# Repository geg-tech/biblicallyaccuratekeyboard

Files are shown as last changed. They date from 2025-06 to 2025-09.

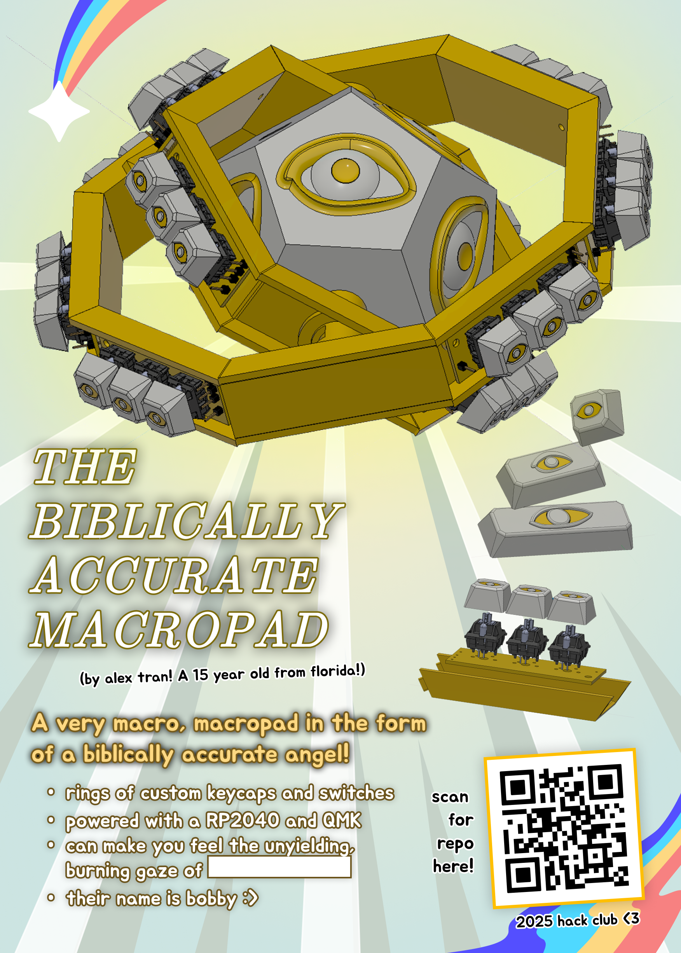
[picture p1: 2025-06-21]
extras/highway magazine.png

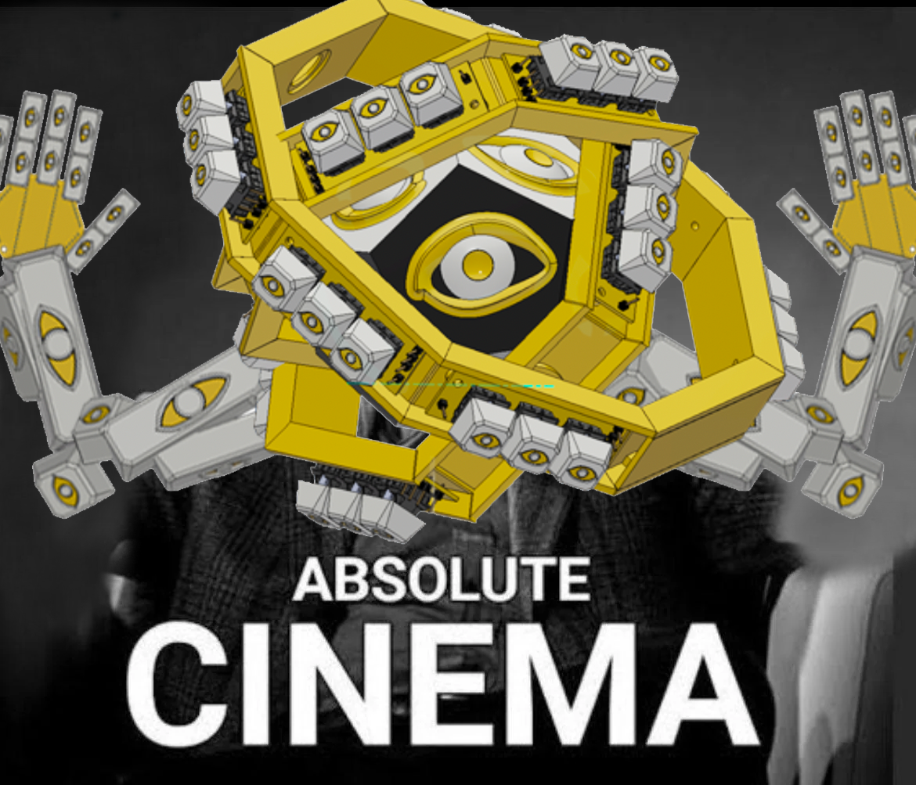
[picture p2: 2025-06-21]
extras/absolute cinema.png

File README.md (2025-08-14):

# The Biblically Accurate Keyboard


This is a custom, 3d-printed keyboard made to resemble a biblically accurate angel, powered by a Raspberry Pi Pico RP2040. <br/>
> see the keyboard working [here](https://youtu.be/EbvpPsTKe3c)!

My intial goal for this project was to just simply make something cool for the summer and to keep me occupied, but soon grew into a very complex CAD and art project that I had loads fun working on (and also served as great Fusion 360 practice for school). <br/>

I learned lots of useful techniques in Fusion 360, such as the Surface modeling tools, Create Form, and the 3D Sketch feature, which I will use extensively in my other work like future hardware projects, school work, and for my team in VEX Robotics. I also plan to show off this project to my high school's IRL Hack Club to encourage more students to join Hack Club :3 <br/>

The keyboard is powered with a RP2040 running QMK, which is soldered into a PCB in the center dodecahedron, and has external rings of key switches surrounding the center, all wired to the center PCB. <br/>

To fit the biblically accurate angel theming, the keyboard has a common motif of eyes, which is often seen in interpretations and drawings of biblically accurate angels. The case is also made out of gold PLA filament, with the center, keycaps, and some decorations painted white to fit the color scheme often associated with angels. <br/>

## CAD
regular view
exploded view <br/>

## PCB + Wiring Diagram
### Schematic
schematic <br/>

### Center PCB (dont mind the raspberry pi being a neon green)
center pcb view
center pcb top view
center pcb bottom view <br/>

### Switch PCBs


 <br/>

### Wiring Diagram
 <br/>

## BOM
| Item  |  Purpose | Price | Source |
| --- | --- | --- | --- |
| SUNLU Gold PLA Filament | Filament for the case | $19.99 | Amazon |
| Switch PCBs  | Houses the switches in the rings | $5.20 | JLCPCB |
| Center PCB  | Holds the RP2040 and connects to the PC | $2.00 | JLCPCB |
| Yellow 26 AWG Wire | Holds the switches and wires to the center | $3.57 | Aliexpress |
| Outemu Blue Switches | Switches to detect user input/presses | $0.99 | Aliexpress |
| RP2040 Microcontroller | Communicates to the computer, detect switch presses | $2.56 | Aliexpress |
| 3D Printer | Manufactures the keyboard case | Owned |  |
| Soldering Iron | Assembles the PCBs, can weld case to seal cracks | Owned |  |
| Keycaps | Makes switches more comfortable to use | Owned (printing |  |
| Cable | Allows connection between RP2040 and PC | Owned |  |
| Super Glue | Secures parts of the case to each other | Owned |  |
| M3 Screws (6mm, 10mm) | Allows for PCBs to be attached to the case | Owned |  |
| ------------- | ------------- | ------------- | ------------- |
|  |  |  | **Subtotal: $34.31**  |
| Amazon: $28.28 | JLCPCB: $18.81 | Aliexpress: $11.74 |  **Total (tax + shipping): $58.83** |

## additional notes and whatnot
* The case is costs around **466.37** grams of filament, and my current spool of black PLA is running really low (<100 grams left)
* The case will be assembled inside-out (starting from the center, threading the wires through the appropriate connectors before permanently attaching PCBs/ring sections
* JLCPCB is used instead of PCBWay due to the $20 coupon announcement to save costs by Hack Club HQ
* The keyboard will be programmed via QMK or KMK and after the keyboard is built

**special thanks**
* *Adedayo Adeleke* on Slack for giving me some microcontroller recommendations early on
* *Atrocious* on Slack for giving me a rundown on how to add 3D models to the PCB previewer in KiCad
* My friends and the many people who liked my work and encouraged me to continue working on the absolute trainwreck that is Fusion
* *alexren* on Slack for helping me and a bunch of others on getting their JLCPCB coupon working
* Special thanks to Hack Club and the people behind Highway for making this possible :D

**Inspirations** <br/>
* The indie game *ULTRAKILL*, specifically the angelic enemies named *Virtues* and the upcoming FRAUD update
* The Roblox game *Block Tales*, specifically the final boss of Demo 4, *The Ancients*

angel <br/>
The angel is also called bobby :)))) <br/>

A badge of a Cerberus and a raccoon laughing together, with the text "HIGHWAY" and "HACK CLUB" beside them.

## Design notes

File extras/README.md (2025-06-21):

# ay wasup hello
this is a folder containing a bunch of random stuff and artwork from the project that I felt like sharing <br/>
contains stuff like scrapped cad models, my highway magazine page, shitposts related to this project, etc. <br/>

highway magazine
looks inside
absolute cinema
biblically accurate macropad

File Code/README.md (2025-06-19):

# uhm what
the code here is currently a placeholder for what the final firmware *should* be! It was made with QMK, and will be changed once I get the macropad built for an easier time customizing which buttons are which (since I can test it on the spot) <br/>

## UPDATE!!!!!
this new code now uses QMK's custom firmware features! the .uf2 file is the compiled firmware uploaded to the RP2040, while the two .json files are part of the adafruit/pico_pad keyboard folder thingy idk <br/>
* keyboard.json replaces the premade one in qmk_firmware/keyboards/adafruit/pico_pad, while the keymap.json file goes into the keymaps folder (and into the desired keyboard folder if made)

vehicular

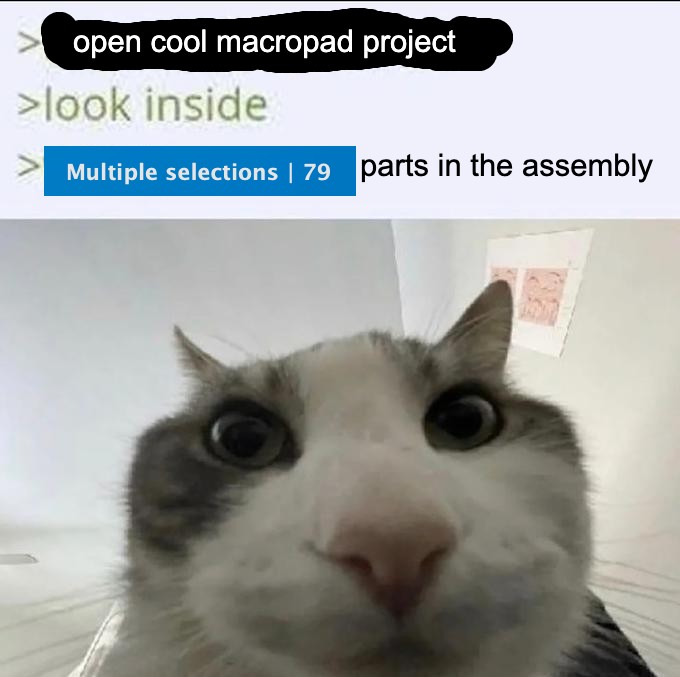
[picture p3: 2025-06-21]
extras/looks inside.jpg

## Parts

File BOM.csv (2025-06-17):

Item | Purpose | Source | Price | Subtotal | Total (tax + shipping) | Link
SUNLU Gold PLA Filament | Filament for the case | Amazon | $19.99 |  |  | https://www.amazon.com/SUNLU-Filament-PLA-Dimensional-Accuracy/dp/B0CJLT7Z9M
Switch PCBs (JLCPCB) | Houses the switches in the rings | JLCPCB | $5.20
Core PCBs (JLCPCB) | Houses the RP2040, connects to switch PCBs | JLCPCB | $2.00
Yellow 26 AWG Wire | Connects PCBs and the RP2040 | Aliexpress | $3.57 |  |  | https://www.aliexpress.us/item/3256805920016063.html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
Outemu Blue Switches | Switches to detect user input/presses | Aliexpress | $0.99 |  |  | https://www.aliexpress.us/item/3256802192387196.html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
RP2040 Microcontroller | Communicates to the computer, detect switch presses | Aliexpress | $2.56 |  |  | https://www.aliexpress.us/item/3256803184741525.html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
3D printer | Manufactures the keyboard case | Owned
Soldering Iron | Assembles the PCBs, can weld case to seal cracks | Owned
Keycaps | Makes switches more comfortable to use | Owned (printing)
Cable | Allows connection between RP2040 and PC | Owned
Super Glue | Secures parts of the case to each other | Owned
M3 Screws (6mm and 10mm) | Allows for PCBs to be attached to the case | Owned
 |  |  |  | $34.31 | $58.83

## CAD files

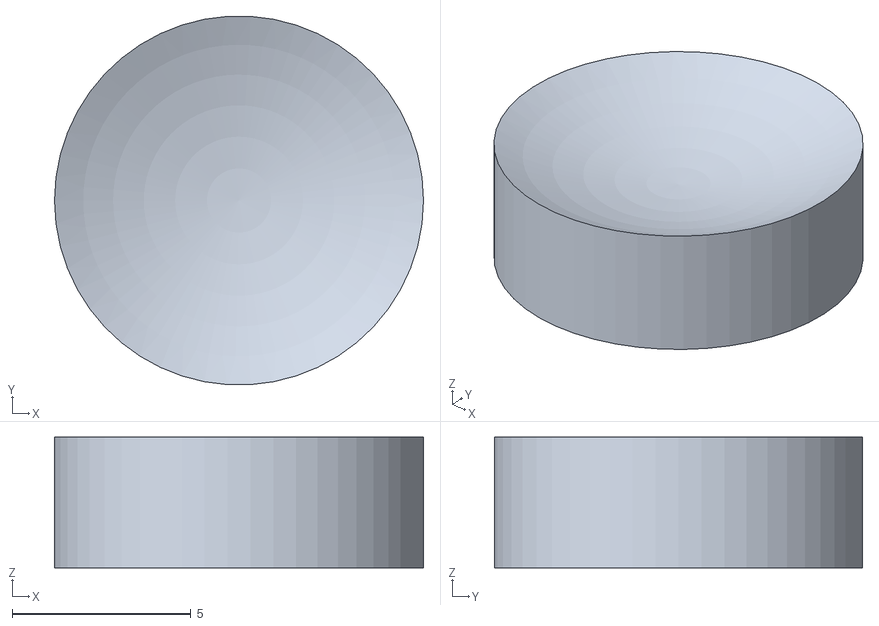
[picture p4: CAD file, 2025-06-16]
CAD/Center/center eye 3.stl
10.3 x 10.3 x 3.66

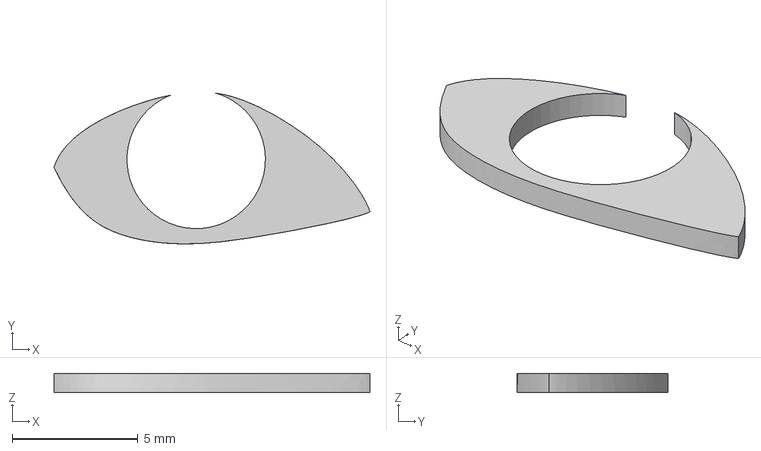
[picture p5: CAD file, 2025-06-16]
CAD/Keycaps/eyecap 2-wide sclera.step
12.6 x 6.00 x 0.762 mm

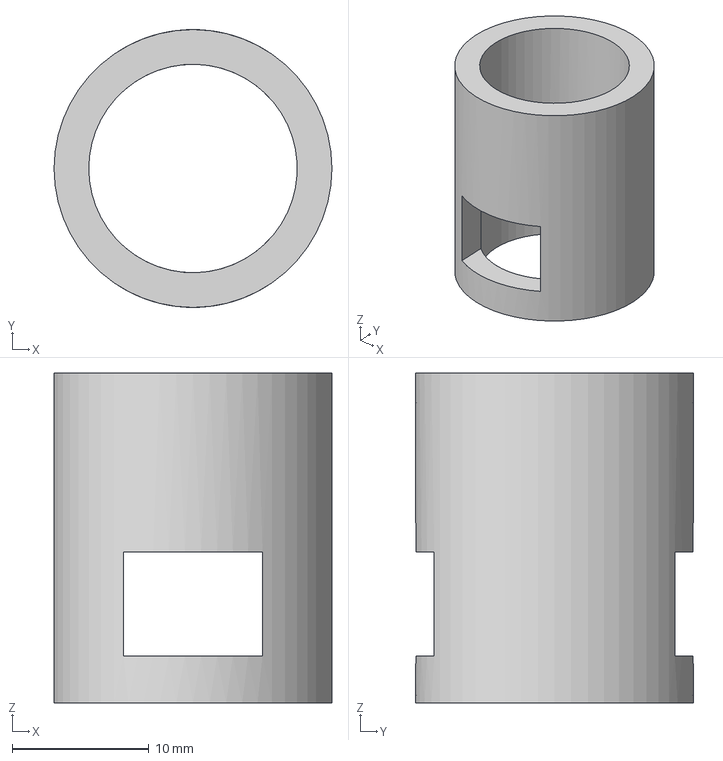
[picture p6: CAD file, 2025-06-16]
CAD/Sections/inner-outer connector.step
20.3 x 20.3 x 24.1 mm

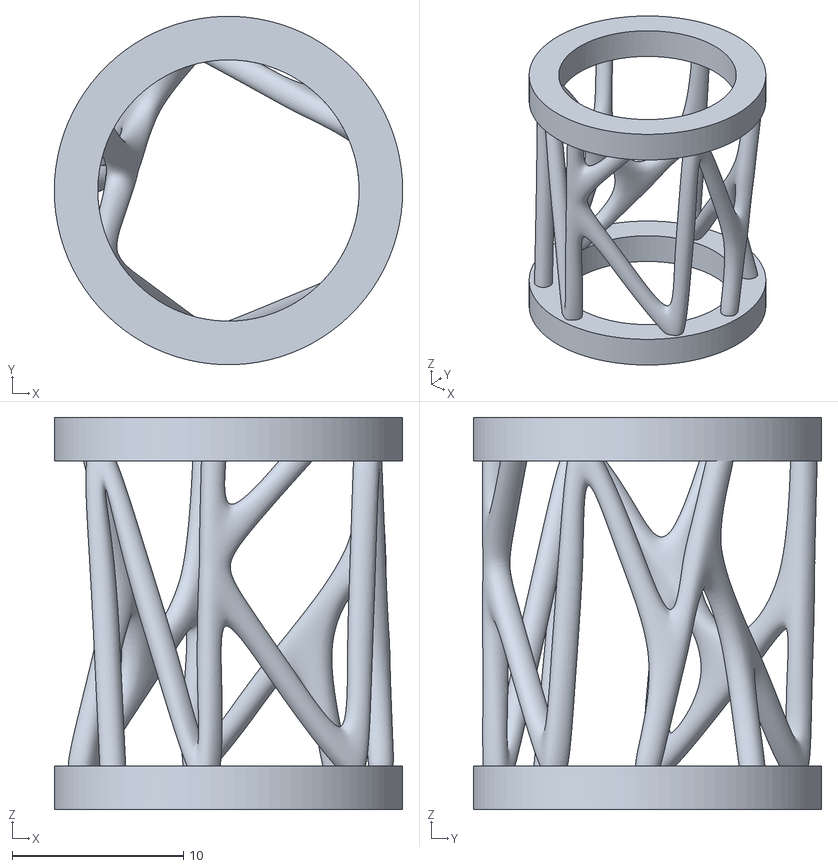
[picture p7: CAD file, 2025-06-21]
extras/inner-outer connector v1.stl
20.3 x 20.3 x 22.9

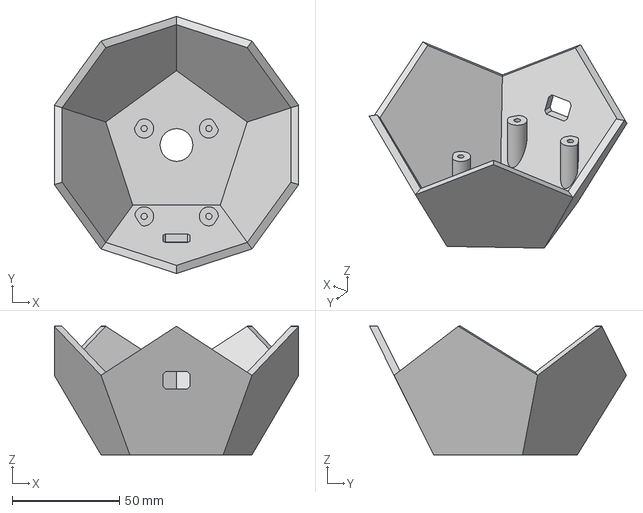
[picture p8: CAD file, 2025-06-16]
CAD/Center/core half 1.step
114.1 x 120.0 x 60.0 mm

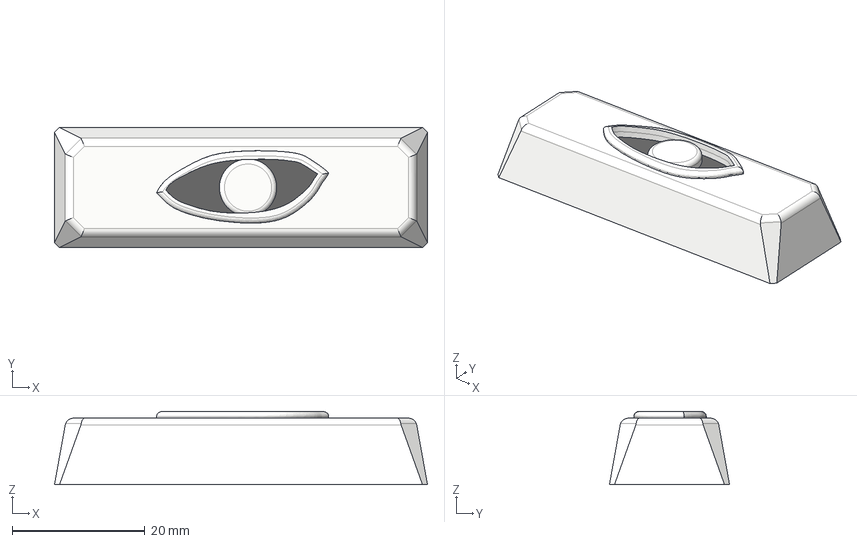
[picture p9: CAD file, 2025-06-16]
CAD/Keycaps/eyecap 3-wide.step
56.2 x 18.1 x 11.0 mm

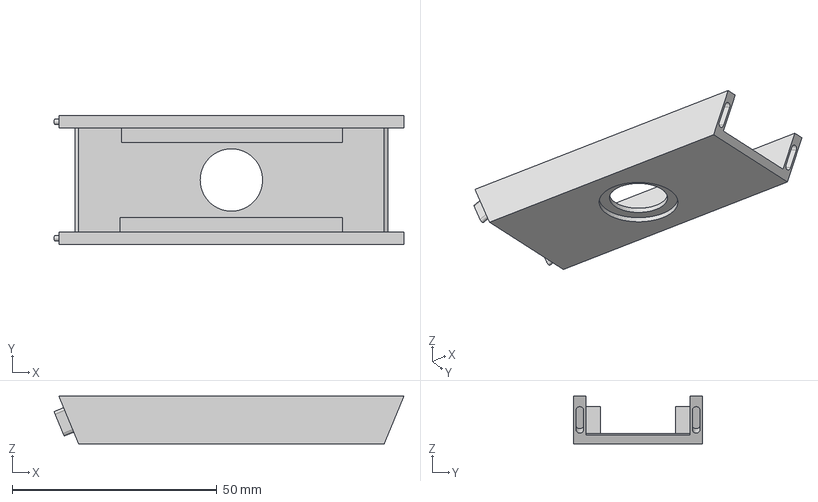
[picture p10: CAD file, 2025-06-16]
CAD/Sections/outer ring opening section.step
85.5 x 31.5 x 11.7 mm

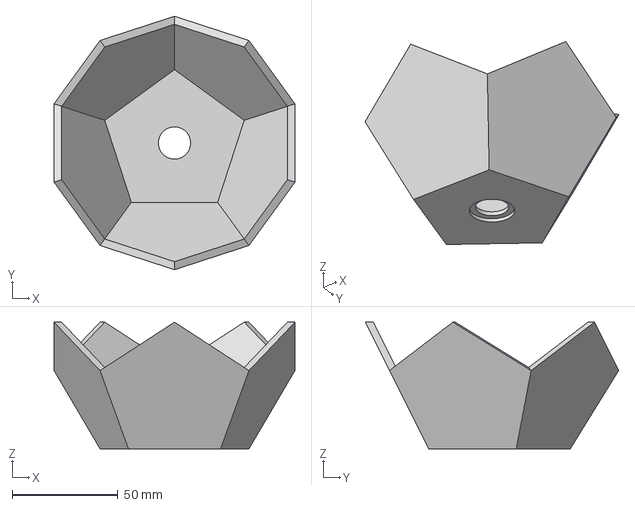
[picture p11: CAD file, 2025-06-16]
CAD/Center/core half 2.step
114.1 x 120.0 x 60.0 mm

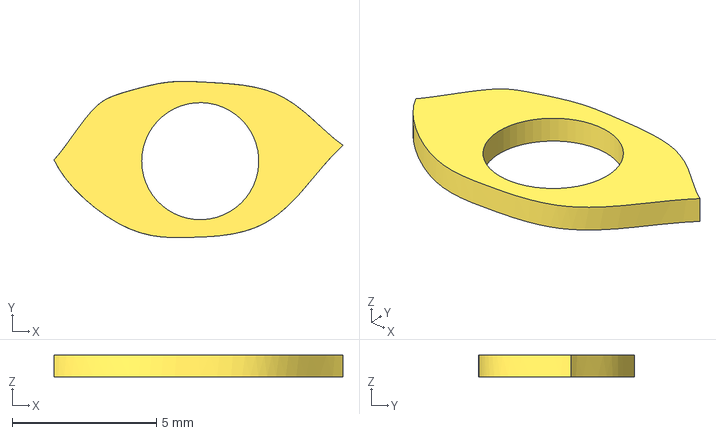
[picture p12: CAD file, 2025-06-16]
CAD/Keycaps/eyecap 1-wide sclera.step
10.0 x 5.43 x 0.762 mm

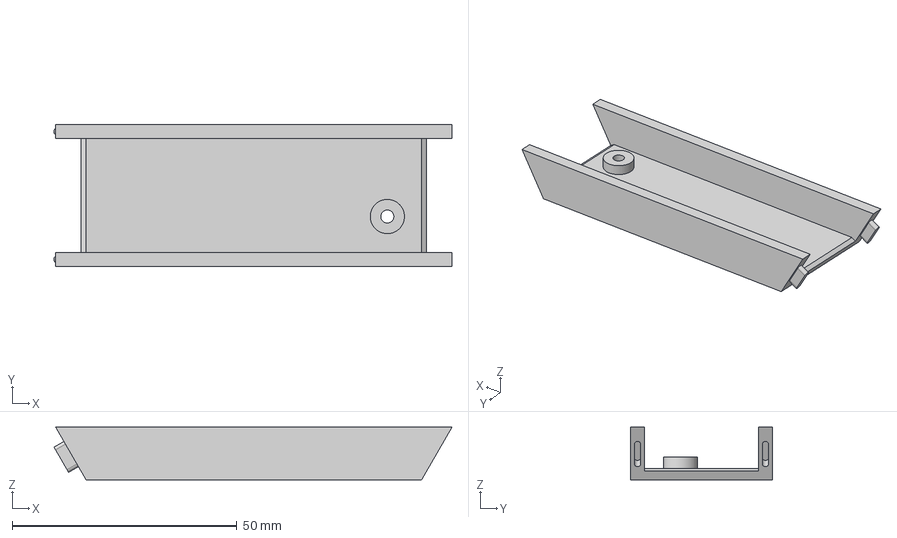
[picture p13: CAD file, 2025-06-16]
CAD/Sections/inner ring section.step
88.5 x 31.5 x 11.7 mm

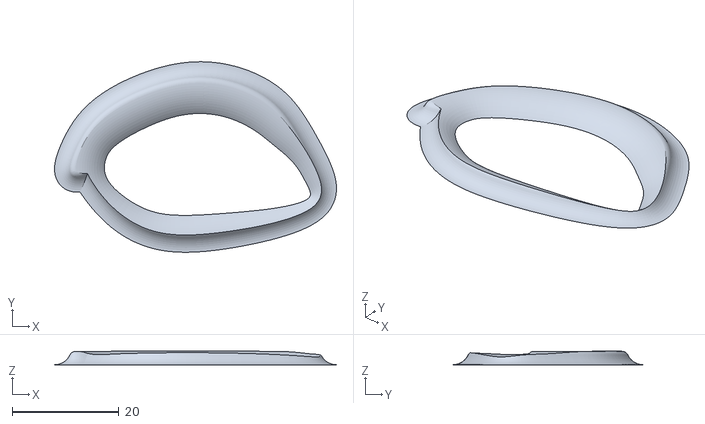
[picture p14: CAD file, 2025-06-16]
CAD/Center/center eye 1.stl
53.0 x 35.8 x 2.54

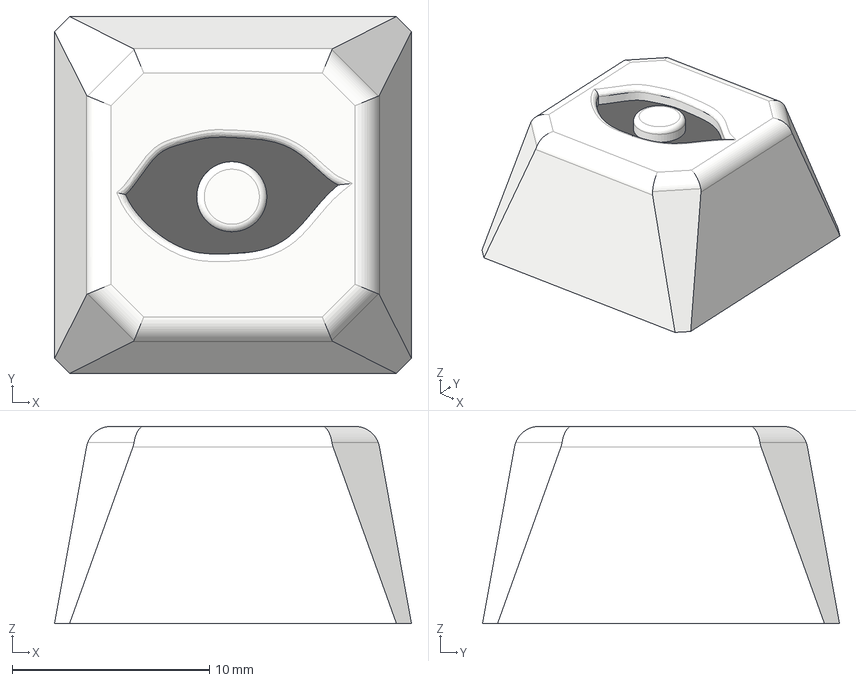
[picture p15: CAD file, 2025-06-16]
CAD/Keycaps/eyecap 1-wide.step
18.1 x 18.1 x 10.0 mm

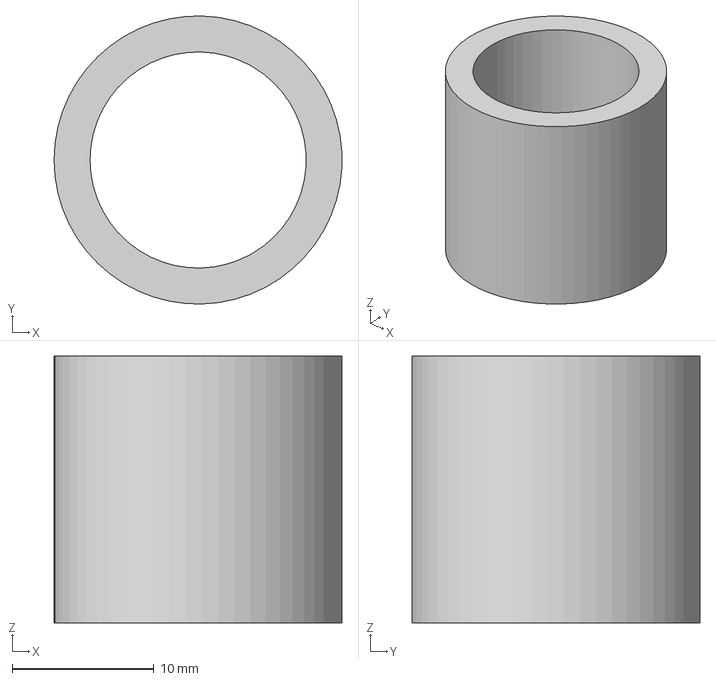
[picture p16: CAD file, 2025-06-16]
CAD/Sections/core-inner connector.step
20.3 x 20.3 x 18.8 mm

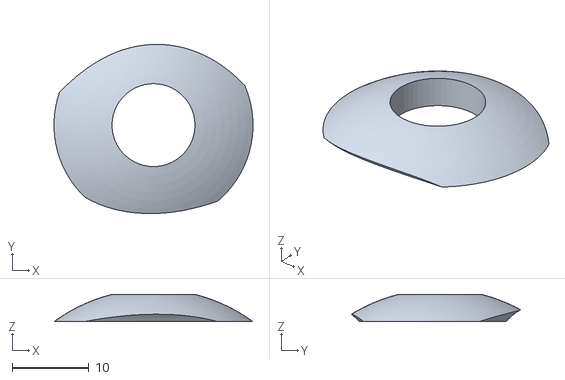
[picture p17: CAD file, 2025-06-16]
CAD/Center/center eye 2.stl
25.9 x 22.1 x 3.56

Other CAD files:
CAD/Keycaps/eyecap 2-wide.step
CAD/Sections/inner ring opening section.step
CAD/Keycaps/eyecap 3-wide sclera.step
CAD/Sections/outer ring section.step
CAD/Sections/outer ring opening plate.step

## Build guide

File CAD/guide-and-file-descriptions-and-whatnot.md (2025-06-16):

## just a quick guide to the cad models since there's like a billion different parts lmao <br/>

* **Sections** - 7 files; The models for the sections that combine to form the rings. Comes in inner and outer variations that form the inner and outer rings (duh) when put together. Also contains a plate that is placed on the outer ring section with the hole for aesthetics, as well as the parts that connect the rings and center together.
* **Keycaps** - 6 files; The models for the custom keycaps. Each keycap comes with an additional model for the sclera
* **Center** - 5 files; The models for the center of the macropad. Contains the two main shells that form the center, as well as the decorative eyes placed on the sides of the center. <br/>


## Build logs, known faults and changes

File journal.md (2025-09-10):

---
title: "The Biblically Accurate Macropad"
author: "egg_splats"
description: "Making a biblically accurate angel go click and clack"
created_at: "2025-05-17"
---

# welcome to da journal :)
(fyi dates are in mm/dd/yy cuz 🦅🇺🇸) <br/>
technically its more like a macropad but shhhhhhhhh 🤫 it doesn't have the same ring to it man

## Total Hour Count: 38.5 hours!!!! (at time of submission)
## TOTAL total Hour count: 58 hours!

## 5/17/25 - The Start of Highway
>be me  
>wake up  
>highway announcement  
>wtf  
  
First entry into the journal! Today I brainstormed a bunch of ideas on what to do for highway, such as:  
* combat robot that flips onto opponents with a vertical spinner (slam jam)  
* horse racing robots with mash-able "cheer" buttons that have a very small chance to boost the robot forward  
* irl V1 wings from ultrakill  
  
Ultimately, I decided to choose something that is somewhat within my comfort zone of circuit boards and 3d modeling (though I hope to do the other ones someday),
that being a keyboard in the shape of a biblically accurate angel. I chose this idea due to the existing tutorial on hackpad which should be a great 
stepping stone into this project, while also being unique and funnier from the usual, flat micropads (though I'm unsure if this idea would count as a custom or starter project 🗿).
  
I have some ideas on what the keyboard should look like, with the shape of the board most likely looking like the usual orb angel with the revolving rings of eyes.  
angel go clack
sticky note sketch <br/>

time spent: ~1 hours

## 5/18/25 - Preliminary Designing
second entry ahhh

This morning I hopped on and decided to start on how i wanted the PCBs to look like. I made a preliminary model of what the keyboard should look like, as well as some research on
possible microcontrollers.
* currently im thinking of using a rp2040-ZERO microcontroller due to the small size and large amounts of pins (20 switches from what i counted), possibly could also use a larger microcontroller like an esp32 from what i read (credit to Adedayo Adeleke on slack for telling me about the rp2040-zero)  
* the microcontroller could be located in the center of the angel, with the outer pcbs containing the switches being wired through the supports using copper contacts and soldered on wires  
* could also use flex pcbs or ribbon cables to manage the wiring more efficiently, though im completely new to them  
preliminary 3d model  
possible wiring  

>sometimes its not about the ergonomics, batman... <br/>

time spent: ~3 hours modeling and sketching

## 5/23/25 - Prototyping Electronics
5 days later from the second entry but we ball (too busy being sleepy and playing balatro)

I didn't get much done today since I was on call with friends for most of my time after school, but I managed to create a type of "testing platform" for the wiring for my keyboard.
Currently, I'm using a Raspberry Pi Pico WH and push buttons from my old Sprig to simulate the keyboard, but couldn't get it to work (probably due to me uploading the firmware wrong
and/or apple not accepting it as a keyboard, xd)

I also want to remake the preliminary model of the keyboard, since it doesn't look much like the biblically accurate angels depicted before (the rings being too large, the center being too small, etc.)  
quick lil prototype <br/>

time spent: ~3 hours (building prototype and bumping my head into the firmware-shaped wall)

## 5/24/25 - it worked :D
IT WORKS!!!!!!!!!!!!!! (and by it the prototype)

I tried finagling with raspberry pi pico code found on adafruit and the hackpad website, but eventually got it working with the QMK Keyboard Configurator using the adafruit/pico-pad configuration.  
I plan to change up to code the keyboard by myself for an easier time tweaking the keyboard, but this currently shows that my wiring idea for the core microcontroller and outer PCBs works.  
the prototype works (in wiring)  
Next should hopefully be another remodel of the current design, followed by PCB design and the first iteration of the keyboard! <br/>

time spent: ~2 hours

## 5/29/25 - Remodel #1
got a lil carried away with the prototype and made it into a tiny breadboard micropad 🐈‍⬛ (even made tiny little keycaps for the buttons)  
thankfully school is out in florida so its time to LOCK IN  
  
ideas and changes:
* The rings/center should be made of two shells that come together for ease of assembly/printing; the rings are to be made into halves, and then possibly made into quarters to fit on my A1 Mini  
* Ring sections could be connected via gluing, assisted with pins or notches for alignment  
* The outer ring is an octogon and houses ~22 switches, while the inner ring is a hexagon and houses ~12 switches (may vary since i also plan on making custom keycaps for the space/enter/shift/esc keys with the same angelic theme)  
The model is currently using a placeholder board from KiCad, but the size of the board shouldn't really change when I remake it (good)<br/>

fresh and brand spankin new design woo<br/>
also gave the fella some eyes :)))))<br/>

time spent: ~4 hours modeling and figuring out how to make a dodecahedron

## 5/30/25 - PCB Designed
Redesigned the PCBs for the switches today, that's it really  
More specifically...  
* I added another GND hole to allow the boards to be "chained" to each other through wires going through GND (should dramatically reduce the amount of wires needed for GND)
* ^ i also tested this with the same raspberry pi from the prototype with a chain of breadboard power rails  
* Centered the switches on the board  
* Added a M3 screw hole to the board for easy attachment to the case (I could also hot glue the pcbs to the case if one screw is inadequate but the spacing should be just right for the boards)  
* Added eyes to the back silkscreen because :eye:  
board  
board2  
board3 <br/>

time spent: ~2 hours redesigning and routing

## 6/5/25 - Started CAD on the case
damn its already june 😔 <br/>
  
Today (after a long break of block tales with friends) I started modeling the 3d printed parts of the keyboard. <br/>
I made the sections of the rings and found out that it would most likely be easier to print each side of the rings individually, instead of trying to meddle with supports and oddly placed holes if I printed the rings in entire sections. <br/>
I also added small slots on the sides of the sections to aid in alignment and gluing, since it would most likely be very difficult to glue and keep together an entire polygon of 3d printed parts lmao <br/>
fusion design of one of the 6 inner sections <br/>
Once I had the sections made, I printed out two pieces to test the tolerances. The parts fit together nicely, but they left a large (and honestly pretty ugly) gap between the two sections. <br/>
I did some research on how to fix this, and found out that I can seal up the gap and join the parts using spare filament and a soldering iron. After some time messing around, I managed to seal the gap in a way that looked good enough <br/>
fusion design of one of the 6 inner sections <br/>
btw ignore the crack i was testing how strong the bond was (it was strong) <br/>

time spent: ~1 hour printing, ~3 hours modeling and learning how to weld plastic

## 6/6/25 - Modeled Connectors
oh hey double sixes <br/>
  
Today I modeled the connector pieces that would hold the rings together, as well as the corresponding sections of the rings that attach to the connectors <br/>
Initially, I made the connector similar to those made by organic generative design programs like the one in Fusion 360. I spent a good while wrangling 3d sketches in Fusion, and after modeling and printing it, the design *literally exploded* the moment I applied shear to it lmfao
> (generative design not as in text prompting an AI model but the ones you would see making those weird bony-shaped parts that are supposedly super tough in aerospace applications and stuff) <br/>

GONE. REDUCED TO DUST. 💔 <br/>
I chose the bony shape of the connector initially since it looked cool due to the organic shape, as well as having holes for wires to feed through for the inner ring of switches, but quickly learned that wasn't an option. In return, I remade the connector in a much more boring fashion (literally just a cylinder with a rectangular hole) 😔 <br/>
boring
fancy <br/>

time spent: ~1 hour designing, ~1 hour printing

## 6/8/25 - Created the BOM
This morning I decided to get a headstart on making my bill of materials (totally not procrastinating on designing the core 🦨) <br/>
 <br/>
I considered making another custom PCB to house the microcontroller and the wires, but then realized that it would be be infinitely times cheaper to mount everything to a perfboard inside the core since it most likely won't be visible in the final product (I forgot who mentioned using a perfboard on the Slack but credit to you, I remember their message being something like using a protoboard for a radio of some kind) <br/>
  
I also believe that using a perfboard will allow for greater flexibility in my design, especially if I want to add extra features like LEDs, but may also have the drawback of being annoying to design around/assemble compared to a custom PCB. <br/>
Currently, almost all the prices are not accounting for tax + shipping, but should be a good start (expect the BOM to be nearly finished near the end of the day, its morning as of writing lol) <br/>

***uh oh future update from the afternoon***
Turns out adding another PCB to the PCBWay order doesn't cost nearly as much as I expected! (5 dollars more and an extra dollar to shipping if included with the switch PCBs) <br/>
While a perfboard *would* still be cheaper by a margin of a few dollars, I had no luck finding the exact hole dimensions for the perfboard I found on Aliexpress, which would make designing the core of the keyboard MUCH harder than it needs to be (not to mention the time needed to learn to assemble a perfboard and the general build quality) <br/>

so yeah pcbs are back on the menu <br/> 
i also picked up some m3 screws and a bottle of super glue on my way to the hardware store today so there's that too :3 <br/>

time spent: ~2 hours of researching/filling out BOM

## 6/9/25 - Designed the core PCB and (parts of the) case
teehee funny 69 date <br/>

Today I designed and finished the PCB that will hold the RP2040 and wires from the switches. <br/>
The center of the PCB holds the RP2040 microcontroller, which is connected to multiple holes that will receive input from the switches on their own PCBs. The holes also contain GND to string throughout the switch PCBs. While choosing the footprints, I realized that I had an odd number of pins heading out (split between 12 and 11 pins on each side), so I also added a hole for 3.3V in case if I ever want to add something extra like an LED as a power light or aesthetics. <br/>
uhh <br/>
The board also looked pretty *empty* and *sad* so I threw in some inside jokes from my friend group, as well as my school's Hack Club logo (made by yours truly :3). On the back I also made a picture of the core of the macropad, using Fusion 360 to create the dodecahedron and Figma to create a solid outline and the custom text for the macropad.<br/>

 <br/>
i also affectionately named the macropad bobby <br/>

After designing the core PCB, I got to work making the case for the center of the macropad. I remade the dodecahedron so I could separate it into halves, making sure the thickness did not extend perpendicular to the faces so the halves could be interlocked with each other. After that, I added a 0.6 in. wide hole to fit the connectors from the rings. <br/>
 <br/>
Once I got the PCB imported into the Fusion file, I quickly made the screw holes and supports to hold the PCB, as well as a cable hole to connect the PCB and microcontroller to the computer. <br/>

 <br/>
Hopefully tomorrow I can start finishing up the CAD for the center and start working on the aesthetics side of the CAD, such as designing custom keycaps, eye plates that will slot into the sides of the dodecahedron, and polishing up the CAD models. <br/>
time spent: ~4 hours in PCB design and drawing art, ~2 hours modeling

## 6/11/25 - Core CAD model finished and completed BOM
I just finished the CAD model for the center, nothing else really <br/>
heres a picture i guess <br/>
 <br/>

I also spent some time going over and reviewing my bill of materials, taking out parts that I didn't need (M3 screws and super glue) and rechecking parts. For example, the PLA filament in my BOM recently went on sale for ~$2 less, which I should take advantage of. I also swapped over from PCBWay to JLCPCB, due to the recent announcement of a 20 dollar coupon for PCBs and my PCBs costing just under $20. <br/>
 <br/>
time spent: 30 minutes finishing CAD, 1 hour finishing bill of materials

## 6/12/25 - Modeled custom keycaps
Today I made custom keycaps for the macropad. <br/>
I knew that the microcontroller I was going to order (and the current setup of the switches) weren't going to support all 30 switches in the prototype CAD model, which meant that I had to merge some keys to fit the amount of GPIO pins. Because of this fact, I ended up making 3 different variants of the keycaps, each using up one, two, and three spaces for switches. <br/>

I designed the switches around the models found in hineybush's Github repo (found here https://github.com/hineybush/CherryMX), using the measurements for the keycap stems and adjusting them for my printer's own tolerances and for the general size of the keycaps (18mm x 18mm x 10mm). Other than that, the models for the keycaps are original. I also added designs on top of the keycaps, based around the eyes found on the rings of depictions of biblically accurate angels. <br/>
Overall, I'm satisfied on how they keycaps turned out, but I may also redesign the 2-wide keycap since it the eyes are all skewed compared to the other keycaps. <br/>
1-wide keycap
2-wide keycap
3-wide keycap
3d prints <br/>
Hopefully next should be designing eyes that can be attached to the sides of the center, and then final revisions for submission 🐈‍⬛ <br/>
time spent: ~2 hours designing keycaps

## 6/13/25 - more decorations!!!!! (and failing)
Today I remodeled the 2-wide keycap to have one eye, as well as attempting to create eyes that will be attached to the sides of the center. <br/>
Although the keycap went well (perhaps my favorite keycap out of the three), I struggled to make the eye for the center. At first I went with using the *"Create Form"* tool in Fusion, making a sketch and creating a pipe with it, but soon ran into issues trying to make it "smooth" into the surface. <br/>
 <br/>
After that didn't work, I tried using the Fillet tool to make it smooth into the surface, but spent an eternity bashing my head against fillet size errors. In the end, I ended up giving up for the day since it was already pretty late into the night (and the fact that Fusion's rendering was tweaking out). <br/>
but anyways cool keycap :D <br/>
 <br/>
I also realized that the inside parts of the eyes were *really* thin (about 1 pla layer), so I also ended up thickening the keycaps there. <br/>
time spent: ~3 hours modeling

## 6/14/25 - that eye that i hate (finished it)
I finished that damn eye <br/>
I ended up making the eyelids by using a regular extrude command, combined with large fillets to create that smooth shape that makes it look like it is part of the surface. After that, I used a revolve tool to create the eye, as well as the iris. All of the parts in the eye are different parts, with the eyelids and iris planned to be colored gold in contrast to the white of the center/eye. <br/>

I also revamped the ring sections that feature the holes that connect to the center of the macropad, removing the screw holes (idk why i put them there) and adding a cover plate to the outer ring variant. <br/>
new eye rah i hated this part
ooh cool new sections <br/>

also here's the full peeper with all the modeled cad and stuff added on (too lazy to add keycaps rn so tomorrow) <br/>
 <br/>
time spent: 2 hours modeling and creating the full CAD

## 6/16/25 - OUGH ITS DONE (the cad)
This morning I colored and added the keycaps to the model I made on the 14th and it looks COOL AS FLIP!!!!!!!!!!!!!!!!!!!! <br/>
 <br/>
Since the CAD is now done, I can now focus on setting up the rest of the GitHub page for submission. I uploaded the all the CAD files, as well as the revised PCB files, and double checked the BOM. <br/>
time spent: ~1 hour

## 6/17/25 - the END!!!! (until i get approved and build it)
Today I totaled the amount of filament needed to print the case in Bambu Studio, totalling to an amount of **466.37 grams** (i think), wow! <br/>
 <br/>
I also worked on finishing up the GitHub, filling out the README and polishing the BOM and uploading it as a csv file. <br/>
I considered uploading some form of firmware as well, but I feel like it would be easier to receive the parts first, then code the macropad once assembled, rather than trying to guess how the ordered RP2040 will behave. Coding the macropad once it is assembled or being assembled will also allow me to adjust the commands on the switches in real time, which may be easier than trying to figure out which switches are connected to each GPIO pin in the final result (aka, coding is a later problem). <br/>

time spent: ~3 hours filling out README, polishing BOM, and tallying filament costs

## 6/18/25 - after the submission...............
damn a highway design competition the day after i submit 🥀 (its ok tho)

Today I started tinkering around with the QMK firmware, seeing if I could make it do some cool stuff while I wait for the project to be reviewed. <br/>
At the start of the project and in the prototypes, I used the web-based [QMK configurator](https://config.qmk.fm/). This worked for basic wiring and prototyping, but was rather limited in what I planned to do. I used the adafruit/pico_pad keyboard, which was only limited to 21 switches in a 3x7 matrix, and I soon realized that I needed extra switches/GPIO when making the CAD. <br/>

Today, I swapped over to [QMK Source](https://docs.qmk.fm/newbs) to see if it provided more power, and after a while I managed to expand the GPIO limit to 23, then to the full 26 the Raspberry Pi Pico offered (which is more than what is supported on my current center PCB... uh oh) <br/>

 <br/>
(the current "keyboard" is essentially a massive row of 26 keys to the code lmao) <br/>

After realizing I had access to the full 26 GPIO on the Raspberry Pi (I previously thought only 23 were usable due to previous research on forums and testing), I quickly made changes to my center PCB and schematic, adding three new holes for the GPIO pins 26-28. I also added extra labels to mark where the GPIO pins led to. <br/>

pcb 3d view
pcb kicad view idk what its called its that dark blue area where you drag everything and stuff yeah
new brand spankin schematic <br/>
It's a little janky having the three new GPIO holes shoved between the spaces, but having to remake the entire PCB's spacing and layout *really* did not seem fun for the night, plus the fact that moving the screw holes would also mean redesigning the CAD for the center dodecahedron... <br/>
<br/>
time spent: ~1 hour messing around with QMK and firmware, ~0.5 hours fixing PCB and schematic

## 6/19/25 - shopping time
I GOT MY GRANT!!!!! AAHHHH!!!!!! <br/>

Today my project got approved (got an extra point for design :D) and received my $150 grant. The JLCPCB coupon didn't work for some odd reason, so I instead ordered from Aliexpress first, then Amazon. <br/>
edit: nvm the coupon works now! uber super giga thanks to @alexren on slack for helping me and a couple other people in getting their coupon fixed :D <br/>
> (by the way can i mention just how helpful the people behind highway have been) <br/>
> (absolutely wonderful stuff man i love this) <br/>

I also spent some time working on Figma for the magazine, making my page for this project. <br/>

 <br/>

I based the background around common depictions of some form of heavenly eye beaming down light, as well as *Heaven Pierce Her's* cover art for "In Absentia ΛΟΓΟΣ" (did i mention i like ultrakill) <br/>
I also added some extra pictures, such as the custom keycaps and the assembly for one of the ring sections. <br/>

**update**: i had to cancel and reorder my amazon order for gold PLA since I accidentally put in the wrong billing address 💀 <br/>
time spent: ~2 hours making the Figma magazine page and ordering

## 7/6/25 - we back at it
got my pcbs from JLCPCB today
> took like 2 weeks but we got there :peefest:

I got my gold filament a while back but never got around to printing the case. Mainly because I'm lazy, but to also test the PCB fittings/tolerances with the prototype prints I made throughout the design process to see whether or not they would work. <br/>

The switch PCBs attached nicely with the M3 screws, but had a little wobble when I applied pressure on one side of the PCB. The sound or feel wasn't terribly affected from this when I put on some spare Hackpad switches on them, but I could put a little stabilizer in the switch case sections to help prevent this. <br/>



I also added a small 6mm hole to the center case for the purpose of jamming in a screwdriver to hit the BOOTSEC button to iterate on the firmware.



time spent: 1 hour

## POST BUILDING RECAP!!!!!!
i think i was supposed to journal the build process 💀 ill try to recap everything with pictures on my phone as references <br/>

### KEYCAPS
When I got my hackpad parts, I tested the original eyecaps on the milky yellow keycaps that came with the hackpad kit. At first I ws confused why it wouldn't fit on, but soon realized that the stem diameter was too big lmao (was 6mm, needed to be 5.4mm)
Once I got the eyecap model fixed, I went back to my printer and made and painted the rest of the keycaps. I was pretty happy with the quality of the keycaps, but they looked pretty ugly and not like the render, particularly due to the lack of the yellow/gold sclera. <br/>
After one or two hours of printing and gluing the sclera on, I finally had the first parts of the keyboard together (and accidentally glued my fungers together) <br/>
I waited for some time for the Aliexpress parts to come in, and by 7/11 I had the parts on me. <br/>
> forgot to take a picture of the box filled with the finished keycaps but you can see them later on when soldering :sadge:

### THOSE CONNECTORS I HATE (7/18/2025)
As of now, I was testing the parts to see if they fit together correctly, and I noticed that the outer ring would always snap away or disconnect if I tried to assemble it with the connectors. At first I thought it was the sections and the left over support material messing up the measurements, but turns out the connectors were like 0.05mm too tall lol <br/>

I also noticed that the connectors had minimal contact with the other printed parts, which was a sign to design the connectors honestly <br/>

I redesigned the connectors with a flange on the outside, kinda looking like a parabola revolved around the cylinder (idk how to describe it just look at it gng). This was made so I can put glue on the flange and have it contacting both the inside of the groove, as well as the outside surface <br/>

 <br/>

I went through a couple iterations of the connectors, messing up the dimensions AGAIN, but I managed to get it fitting pretty well. I didn't want to glue everything before I made the internals, so I jsut taped everything together for the meantime. <br/>



### CORE (7/22/2025)
This was probably the simplest part tbh <br/>
The print quality on the core was pretty good, but after my experience with my irl sculk shrieker and Hackpad, I wanted to paint over the core to make the white look cleaner and less "printed" in a sense. <br/>



After that, I glued on the eyes (as seen in the picture above). I considered using hot glue or superglue, but I ended up just straight up using an Elmers glue stick for the ease and lack of a visible gap between the eyes and the center.

### RINGS (7/23/2025)
After that, it was time to assemble the ring sections. (on 7/23 because PROCRASTINATION AHHHHHHH) <br/>
I soldered the light blue keyswitches from Aliexpress onto the newly shipped PCBs, snipping off small bits of wire to chain them through the GND vias. <br/>



Once I had the sections chained together, I screwed them into the printed ring sections and glued the pritned sections together. <br/>



### BIBLICALLY ACCURATE WIRING (7/27-28/2025)
I *really* (and i mean it), *REALLY* did not want to do this, but it was pretty much the last step I had before it was completed so <br/>
After soldering on the Raspberry Pi onto the core PCB, I started measuring out the lengths of wire needed to reach every section on the rings. I made up a system to group and categorize the sections and their lengths with sticky notes and tape, but I quickly lost count and ended up just cutting a bunch of excess lmao <br/>



To help with management and threading the billions of wires in this, I twisted the wires together into bunches, leading to this monstrosity of yellow wires you see above. (which reminded me of dreads for some reason) <br/>
Once I had everything in, I screwed in the core PCB and sealed it away forever inside the two halves. I threaded the wires through the different connectors and sections and soldered them to the switch PCBs from earlier. <br/>

shake yo dreads

It was pretty weird trying to solder them, since they were awfully close the the rings (especially the outer ring because they were connected on both sides) but we ball <br/>



After that, the build was pretty much completed! I had to glue up some cracks to prevent it from splitting, but the polygon shape of the rings made the build *surprising* sturdy, so much so that the core halves were locked together without me ever having to glue it together. <br/>

### REDDIT AAAHHHHHH (and magazine)
Once I had the build completed, I could finally unplug my soldering iron and touch grass <br/>
I took some nice pictures outside of the keyboard and made my post on Reddit for the demo form. <br/>

 <br/>
 <br/>

After that, I made a magazine page for the Highway Magazine Volume 2. I used a lot of stuff from the original magazine page, replacing the text to say keyboard (finally) and changing around the details. <br/>

 <br/>

(the large "ring" in the background is actually a really quick Fusion model I whipped up of an octagonal ring like the outermost ring of the keeb :3) <br/>

### TOTAL HOURS: 19.5 hours! (estimation taken from the metadata from my photos, take w/ many grains of salt)
